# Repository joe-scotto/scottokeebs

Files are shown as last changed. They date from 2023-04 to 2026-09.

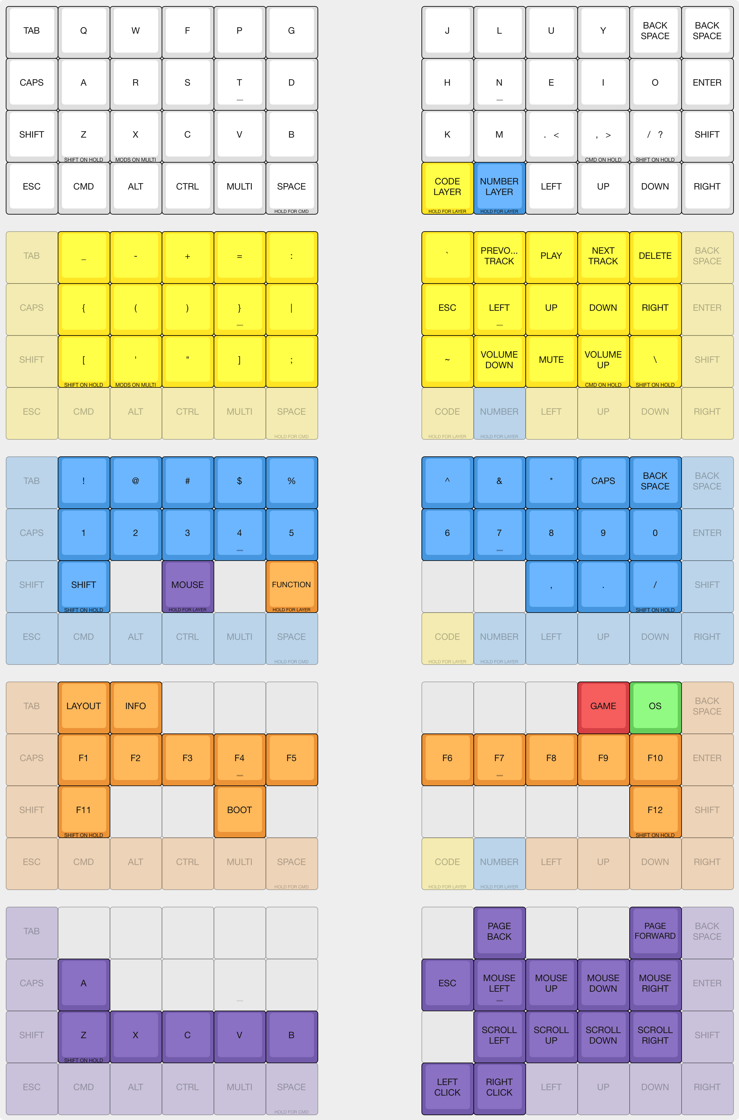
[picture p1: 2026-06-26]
Scotto48/PCB/Firmware/scotto.png

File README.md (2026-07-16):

png

Joe Scotto with his keyboards

ScottoKeebs at its core is an extensive collection of freely available handwired keyboard and macropad projects. It was started in September of 2022 and since then over 19 projects have been released. Most of them fit on a common 220x220mm 3D printer, require minimal support material, and use either an Arduino Pro Micro or a more powerful Raspberry Pi Pico.

# Navigation

-   [Website](https://scottokeebs.com)
-   [Keyboards](https://scottokeebs.com/blogs/keyboards)
-   [Macropads](https://scottokeebs.com/blogs/macropads)
-   [Extras](https://github.com/joe-scotto/scottokeebs/tree/main/Extras)
-   [Discord](https://discord.gg/vN6X3z8eyv)
-   [YouTube](https://youtube.com/joe_scotto)
-   [Recommendations](https://scottokeebs.com/pages/recommendations)
-   [Handwiring](https://www.youtube.com/watch?v=hjml-K-pV4E)
-   [Shop](https://www.youtube.com/watch?v=hjml-K-pV4E)

# Supporting

The ScottoKeebs project is released entirely for free and always will be, however, the development of new boards is completely out of my own pocket. It’s not a particularly expensive project to maintain but does involve quite a bit of time between prototyping and making content related to them.

**If you happen to really enjoy what I do and want to support me, consider [donating](https://donate.stripe.com/eVa14Yev83SmavmbII), [becoming a patron](https://patreon.com/joe_scotto), or purchasing something from my [shop](https://www.scottokeebs.com/shop).**

# License

</a></p>

<p xmlns:cc="http://creativecommons.org/ns#" xmlns:dct="http://purl.org/dc/terms/"><a property="dct:title" rel="cc:attributionURL" href="https://github.com/joe-scotto/scottokeebs">ScottoKeebs</a> by <a rel="cc:attributionURL dct:creator" property="cc:attributionName" href="https://github.com/joe-scotto">Joe Scotto</a> is licensed under <a href="http://creativecommons.org/licenses/by-nc-sa/4.0/?ref=chooser-v1" target="_blank" rel="license noopener noreferrer" style="display:inline-block;">CC BY-NC-SA 4.0

_If you plan on converting a ScottoKeeb to a PCB, I would prefer you don't release the production or design files publicly in order to prevent people from stealing and selling my designs._

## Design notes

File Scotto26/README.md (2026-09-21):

# Scotto26 (SK46)

The Scotto26 is a 26-key split 3x4 keyboard that uses combos for the inner column on a normal layout.

You can read more about the components and how to build it [here](https://scottokeebs.com/blogs/keyboards/scotto26).

Scotto26

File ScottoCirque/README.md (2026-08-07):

# ScottoCirque (SK45)

The ScottoCirque is a 40mm Cirque Glidepoint trackpad module.

You can read more about the components and how to build it [here](https://scottokeebs.com/blogs/macropads/scottocirque).

scottocirque

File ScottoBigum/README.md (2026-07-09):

# ScottoBigum (SK45)

The ScottoBigum is a 17-key wireless macropad scaled up 4 times the normal size and arguably a world record.

You can read more about the components and how to build it [here](https://scottokeebs.com/blogs/macropads/scottobigum-handwired-macropad).

scottobigum

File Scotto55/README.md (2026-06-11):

# Scotto55 (SK42)

The Scotto55 is a 55-key split monoblock ergonomic keyboard with a large center rotary encoder.

You can read more about the components and how to build it [here](https://scottokeebs.com/blogs/keyboards/scotto55-handwired-keyboard).

Scotto55

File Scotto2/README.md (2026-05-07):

# Scotto2 (SK43)

The Scotto2 is a 2 key large button gamepad designed for accessibility.

You can read more about the components and how to build it [here](https://scottokeebs.com/blogs/macropads/scotto2-handwired-macropad).

IMG_6516 Large

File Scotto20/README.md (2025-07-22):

# Scotto20 (SK36)

The Scotto20 is a 20-key macropad.

You can read more about the components and how to build it [here](https://scottokeebs.com/blogs/macropads/scotto20-handwired-macropad).

Scotto20

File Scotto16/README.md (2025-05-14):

# Scotto16 (SK34)

The Scotto16 is a 16-key macropad.

You can read more about the components and how to build it [here](https://scottokeebs.com/blogs/macropads/scotto16-handwired-macropad).

Scotto16

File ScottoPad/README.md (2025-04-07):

# ScottoPad (SK33)

The ScottoPad is an 18-key wireless macropad.

You can read more about the components and how to build it [here](https://scottokeebs.com/blogs/macropads/scottopad-handwired-macropad).

ScottoPad

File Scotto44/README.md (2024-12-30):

# Scotto44 (SK32)

The Scotto44 is a 3x5 (38-keys) or 3x6 (44-keys) split column-staggered keyboard that uses a USB-C cable for the interconnect and has a large 3u action button.

You can read more about the components and how to build it [here](https://scottokeebs.com/blogs/keyboards/scotto44-handwired-keyboard).

Scotto44

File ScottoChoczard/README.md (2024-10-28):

# ScottoChoczard (SK31)

The ScottoChoczard is a wireless split 3x6 ortholinear keyboard that uses Choc switches and a large 750mah battery.

You can read more about the components and how to build it [here](https://scottokeebs.com/blogs/keyboards/scottochoczard-handwired-keyboard).

ScottoChoczard

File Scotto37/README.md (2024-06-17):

# Scotto37 (SK27)

The Scotto37 is a 37-key gasket-mounted 0.25u row-staggered keyboard with a 3u spacebar.

You can read more about the components and how to build it [here](https://scottokeebs.com/blogs/keyboards/Scotto37-handwired-keyboard).

scotto37

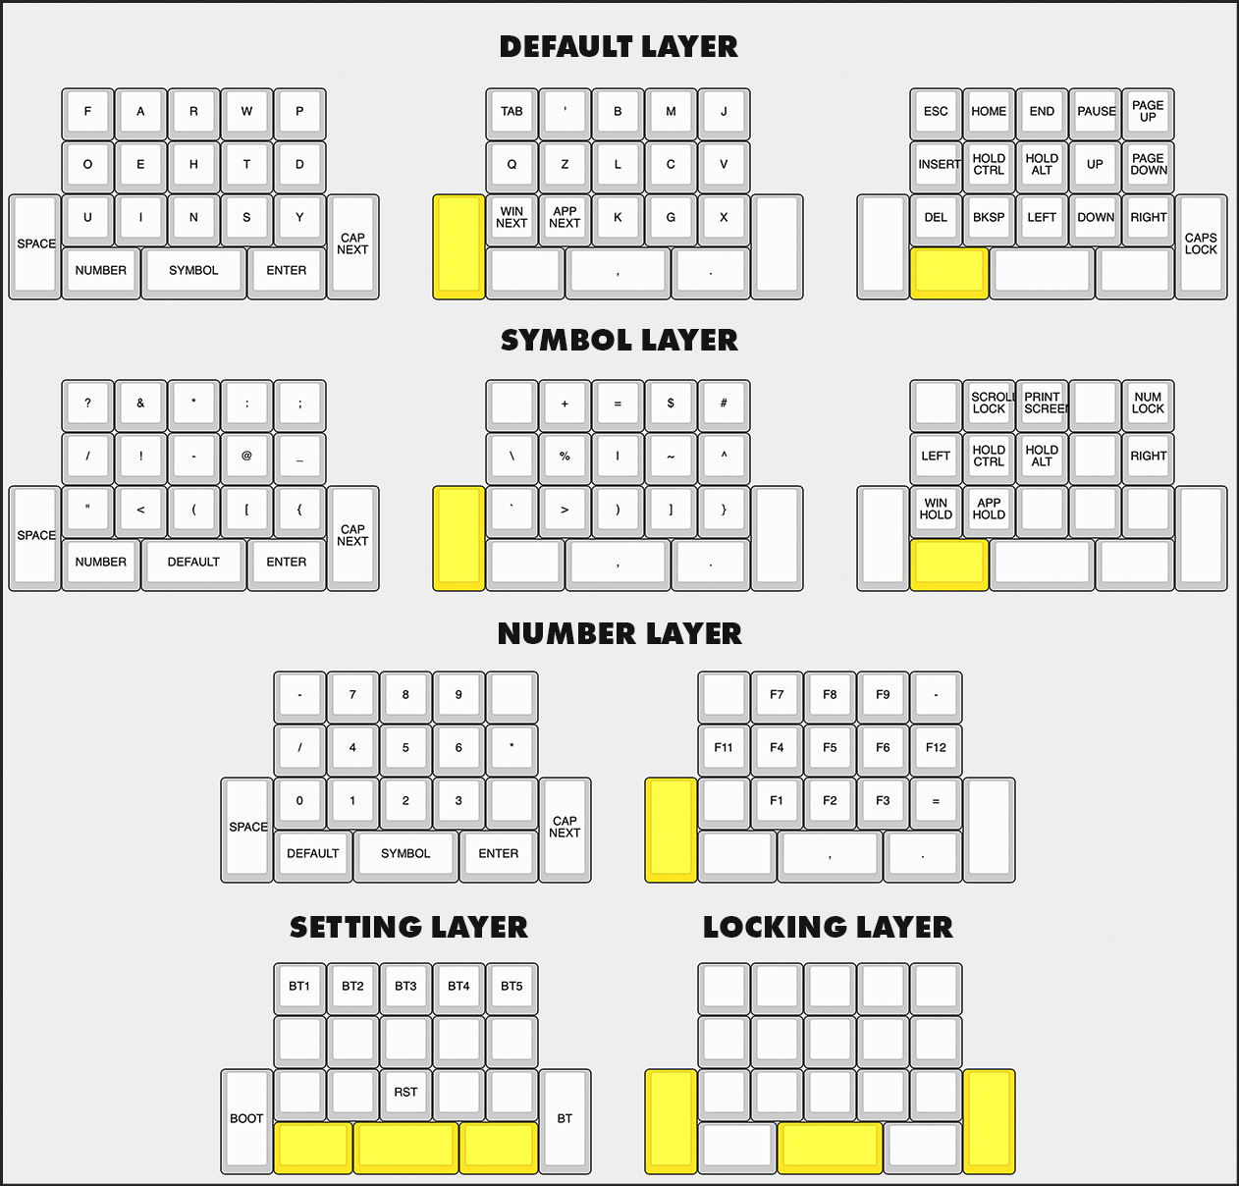
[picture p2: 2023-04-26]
ScottoFrog/Handwired/Firmware/scottofrog.jpg

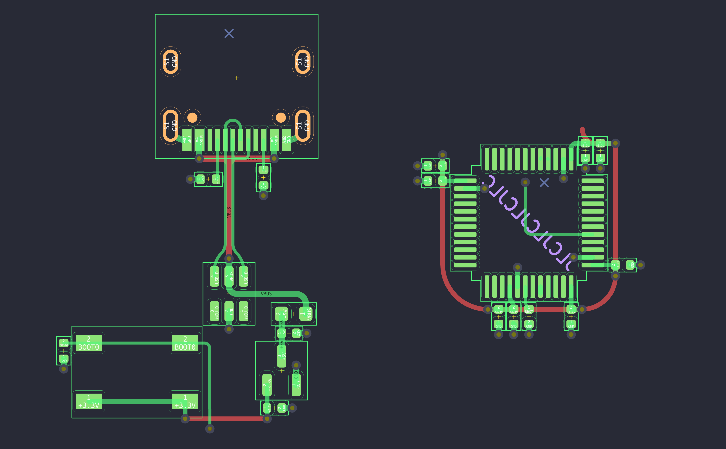
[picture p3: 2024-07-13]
Extras/ScottoModules/STM32F072CBT6/meta/scottomodules.png

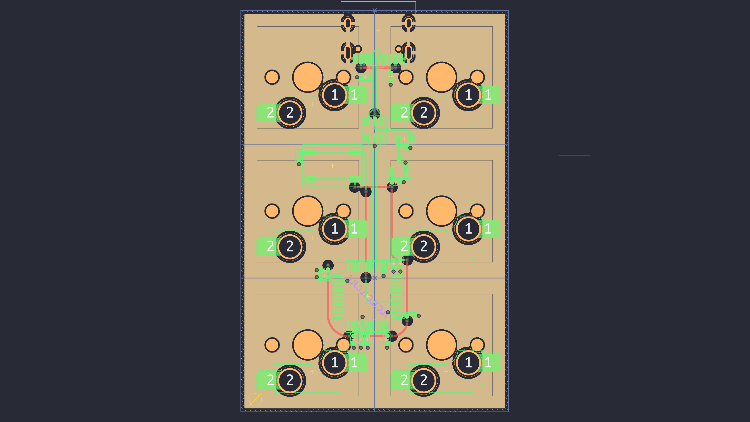
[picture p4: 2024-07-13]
Extras/ScottoModules/STM32F072CBT6/meta/matrix.png

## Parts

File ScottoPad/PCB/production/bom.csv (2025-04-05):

Designator | Footprint | Quantity | Value | LCSC Part #
C0, C1, C2, C3, C4, C5, R0, R1, R2 | TestPoint | 9 | TestPoint
D1, D10, D11, D12, D13, D14, D15, D16, D17, D18, D2, D3, D4, D5, D6, D7, D8, D9 | Diode_SOD-123 | 18 | Diode
S1, S10, S11, S12, S13, S14, S15, S16, S17, S18, S2, S3, S4, S5, S6, S7, S8, S9 | MX_Solder_1.00u | 18 | Keyswitch

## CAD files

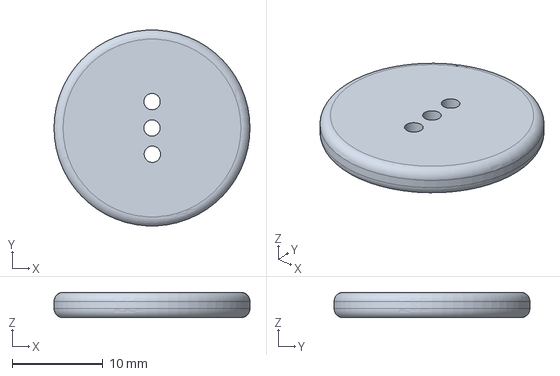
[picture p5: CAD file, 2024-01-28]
Extras/ScottoBender/ScottoBender - Cutter.step
21.6 x 21.6 x 2.80 mm

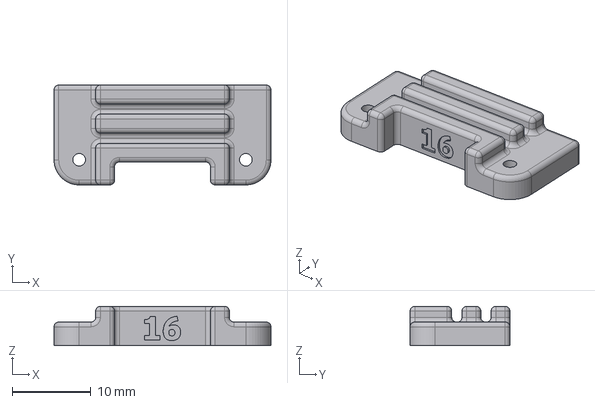
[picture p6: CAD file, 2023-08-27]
Extras/ScottoBender/V1/ScottoBender - ScottoBender (16g).step
27.6 x 12.7 x 5.00 mm

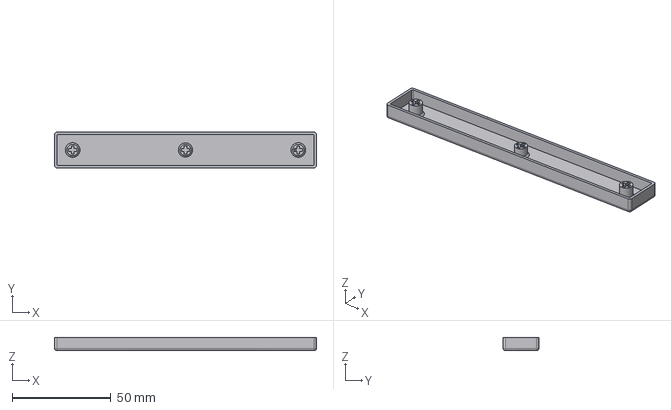
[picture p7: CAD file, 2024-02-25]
Extras/ScottoCaps/Flat/Blanks/ScottoCaps (Flat) - Shapr3D 5.5 Parametric (1)_7.00u.step
132.4 x 18.0 x 6.70 mm

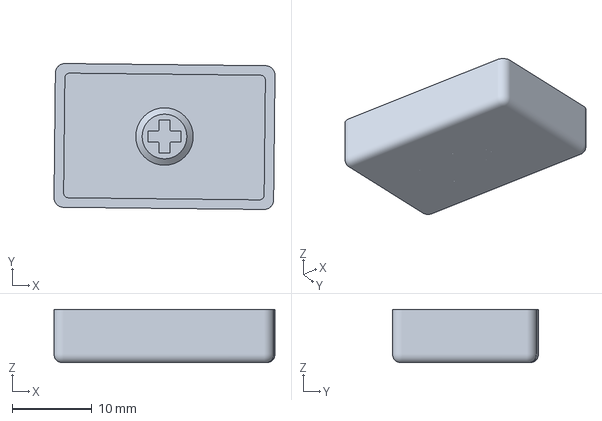
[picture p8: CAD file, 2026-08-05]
Extras/ScottoCaps/Flat/Legends/Alt (1.50u).3mf
27.7 x 18.3 x 6.70 mm

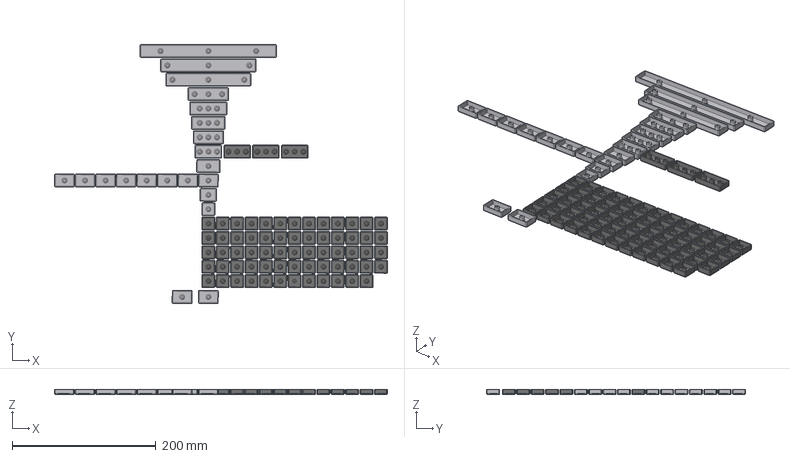
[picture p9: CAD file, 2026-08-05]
Extras/ScottoCaps/Flat/ScottoCaps (Flat).step
463.0 x 360.2 x 6.70 mm
Windows (1.50u)
Delete (1.50u)
Tab (1.50u)
Shift (1.50u)
Control (1.50u)
Alt (1.50u)
Caps Lock (1.50u)
No (1.50u)
Yes (1.50u)
Tilde
0 (2.00u)
Backspace
Tab
Q
W
F
P
G
J
L
U
Y
Semicolon
Slash
FSlash
Enter
Enter (2.00u)
A
R
S
T
D
H
N
E
I
O
Quote
LShift
Z
X
C
V
B
K
M
Less
Greater
Question
RShift
Hexagon1
Triangle1
Circle1
Square1
Hexagon2
Triangle2
Circle2
Square2
Left
Up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

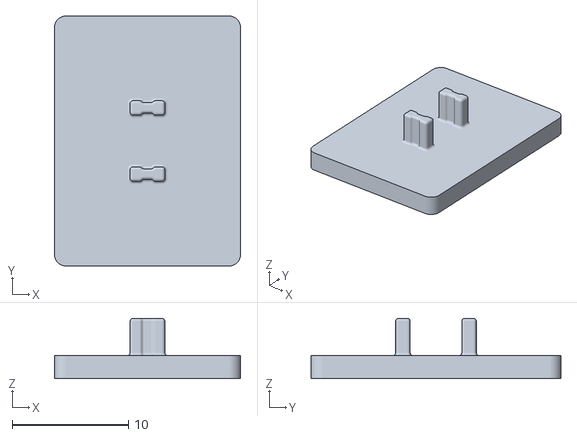
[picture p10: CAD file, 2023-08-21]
Extras/ScottoCaps/Glass/Choc/ScottoCaps (Glass) - 1.25u.stl
16.0 x 21.5 x 5.20

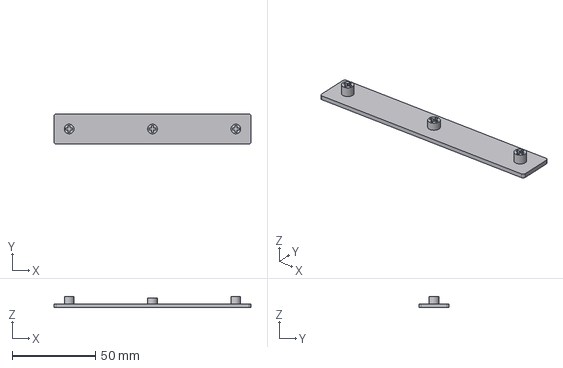
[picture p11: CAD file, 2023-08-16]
Extras/ScottoCaps/Glass/MX/ScottoCaps (Glass) - 6.25u.step
118.2 x 18.2 x 6.60 mm

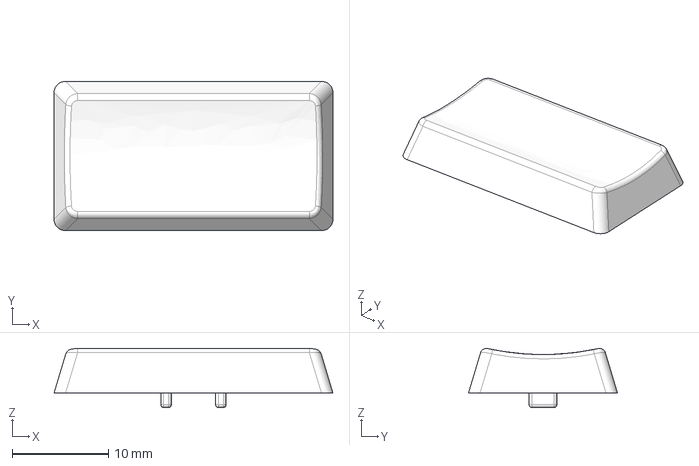
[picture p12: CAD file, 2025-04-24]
Extras/ScottoCaps/Scooped/Choc/Blanks/16x16/1.75u (16x16 - Concave).step
29.0 x 15.5 x 6.14 mm

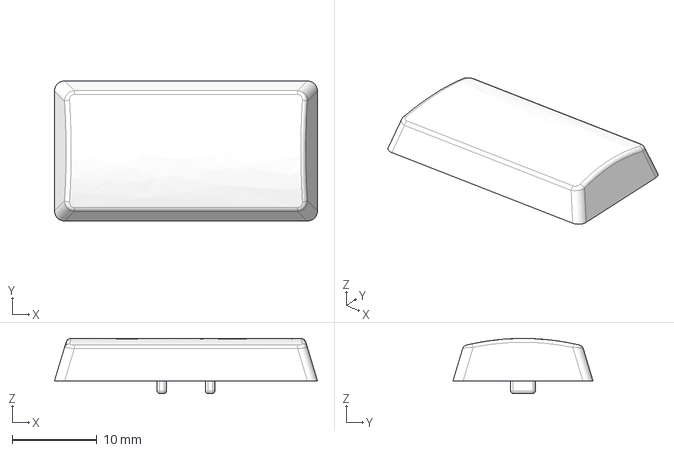
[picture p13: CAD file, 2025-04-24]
Extras/ScottoCaps/Scooped/Choc/Blanks/18x17/1.75u (18x17 - Convex).step
31.0 x 16.5 x 6.50 mm

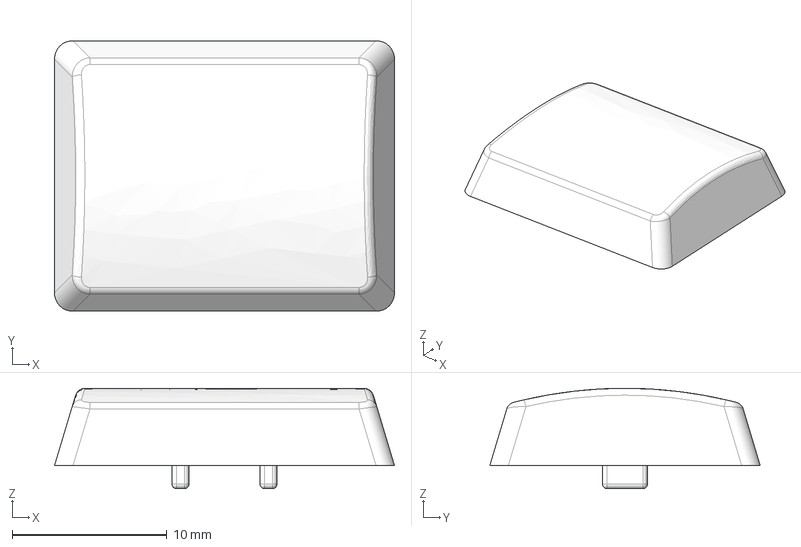
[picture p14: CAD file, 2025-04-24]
Extras/ScottoCaps/Scooped/Choc/Blanks/18x18/1.25u (18x18 - Convex).step
22.0 x 17.5 x 6.50 mm

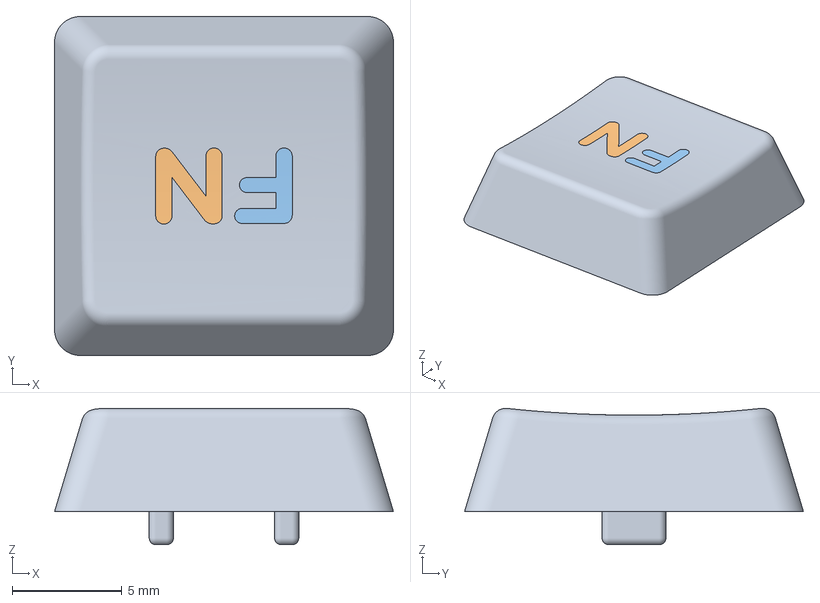
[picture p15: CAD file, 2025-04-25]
Extras/ScottoCaps/Scooped/Choc/Legends/16x16/Function - Text (16x16).3mf
15.4 x 15.4 x 6.20 mm
Keycap
N
F

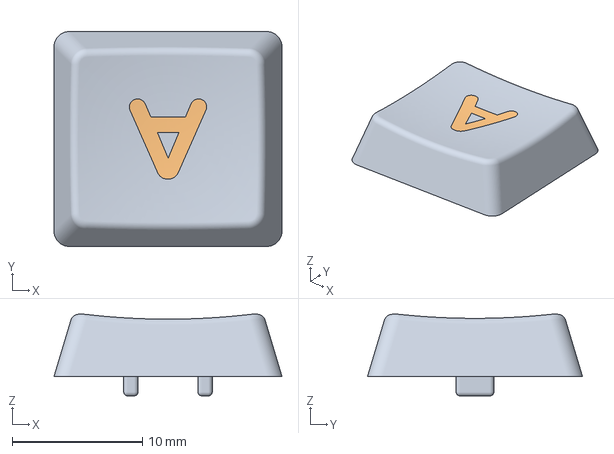
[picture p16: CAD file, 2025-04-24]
Extras/ScottoCaps/Scooped/Choc/Legends/18x17/A (18x17).3mf
17.5 x 16.5 x 6.28 mm
Keycap
Legend

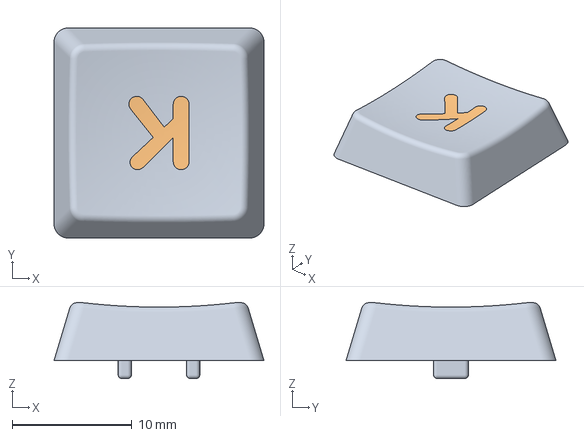
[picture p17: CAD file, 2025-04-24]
Extras/ScottoCaps/Scooped/Choc/Legends/18x18/K (18x18).3mf
17.5 x 17.5 x 6.33 mm
Keycap
Legend

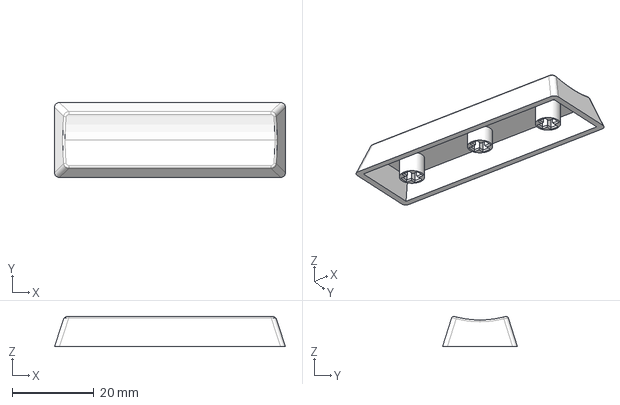
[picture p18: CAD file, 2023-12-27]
Extras/ScottoCaps/Scooped/MX/Blanks/3.00u (Concave).step
56.4 x 18.3 x 7.39 mm

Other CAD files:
Extras/ScottoCaps/Scooped/MX/Legends/Shift (1.50u).3mf
Extras/ScottoCaps/Scooped/MX/Raw/Concave Cutter.step
Extras/ScottoCaps/Scooped/MX/ScottoCaps (Scooped - MX) - Raw.step
Extras/ScottoCaps/ScottoCaps - 2.50u.step
Extras/ScottoBender/Bambu.3mf
Extras/ScottoBender/ScottoBender - Bottom.3mf
Extras/ScottoBender/ScottoBender - Bottom.step
Extras/ScottoBender/ScottoBender - Cutter.3mf
Extras/ScottoBender/ScottoBender - Middle.3mf
Extras/ScottoBender/ScottoBender - Middle.step
Extras/ScottoBender/ScottoBender - Top (Symbol).3mf
Extras/ScottoBender/ScottoBender - Top (Symbol).step
Extras/ScottoBender/ScottoBender - Top.3mf
Extras/ScottoBender/ScottoBender - Top.step
Extras/ScottoBender/V1/ScottoBender - ScottoBender (16g).stl
Extras/ScottoBender/V1/ScottoBender - ScottoBender (18g).step
Extras/ScottoBender/V1/ScottoBender - ScottoBender (18g).stl
Extras/ScottoCaps/Flat/Blanks/1.00u.3mf
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

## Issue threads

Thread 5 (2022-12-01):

Incorrect link

viciousdrop, 2022-12-01:
Hey dude love your stuff. Getting ready to build your 36 board over the Christmas break.

The link in your keyboard read me for Scotto starter goes to Scotto alp. Thought you want to know. Cheers

joe-scotto, 2022-12-16:
Not sure how I never got the notification for this but I fixed it tonight.

Thanks!

Closed 2022-12-16.

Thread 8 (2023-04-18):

Latest Scotto 9 plate files missing screw holes

ValerianClerc, 2023-04-18:
The [latest commit to the Scotto 9](https://github.com/joe-scotto/scottokeebs/commit/64fd981946e17bfb1748774849abb6b54c125160) case/plate `.stl` files has removed the screw holes in the plate.

[Before](https://github.com/joe-scotto/scottokeebs/blob/6471538663b09b30d701e398841e1ddb5251c313/Scotto9/Case/Scotto9%20-%20Plate.stl):
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

[After](https://github.com/joe-scotto/scottokeebs/blob/main/Scotto9/Case/Scotto9%20-%20Plate.stl) (current):
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

joe-scotto, 2023-04-18:
Thank you, fixed in [d236eca](https://github.com/joe-scotto/scottokeebs/commit/d236eca8e393410f7d84a18d1b41dc769da98818).

Closed 2023-04-18.

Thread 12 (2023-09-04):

3D files for Scotto34 PCB Edition?

bobwulff, 2023-09-04:
https://github.com/joe-scotto/scottokeebs/tree/main/Scotto34/PCB

joe-scotto, 2023-09-04:
I made the decision for my PCB boards to close-source everything but the firmware since I release all my [handwired](https://scottokeebs.com/blogs/keyboards) boards completely free.

That said, the Scotto34 is simple enough to design a case on your own if you wanted :)

Closed 2023-09-04.

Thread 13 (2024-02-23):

KiCad files in their own repo

rsescu, 2024-02-23:
Hi. Nice project, love your vids! Just a question, have you considered splitting Extras/ScottoKicad/ into it's own repository. Might be a cool idea to try and get it published as a plugin?

joe-scotto, 2024-02-23:
I thought about it when I put everything together but I instead decided to keep it here as it makes it easier to just link one thing with everything.

Maybe one day I'll look into making it a plugin but no plans currently.

marcuswu, 2024-07-11:
Perhaps use a [git submodule](https://git-scm.com/book/en/v2/Git-Tools-Submodules) to link the KiCad files back?

joe-scotto, 2024-07-12:
Submodules might actually be the solution I look into soon as the repo is starting to approach the 2gb limit. The problem and reason I haven't done anything is that my videos, specifically for Kicad, all show downloading the project and that wouldn't work with submodules. Might be just as simple as linking the new submodule underneath the video.

The other issue with this method is that it starts making it more complex for me to manage. The way I work now is that I just push everything to `ScottoKeebs` because it makes my life easier. In the next few months I'll take a deeper look at this because I am very close to hitting the repo size limit.

marcuswu, 2024-07-19:
I was thinking about it more, and if you wanted the Kicad components under a separate license, it would be nicer under a separate repo. For instance, in order to clear the legality of utilizing these components within a commercial keyboard -- it's clear you don't want the keyboards you've designed sold commercially without making a deal with you, but is it ok to use the Kicad libraries to design a unique design and sell that commercially? If that is the intent, a separate license file within a directory can work, but a separate repository with a different license is clearer.

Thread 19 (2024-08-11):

Release Bambu Studio file for your keycaps?

Avaviel, 2024-08-11:
I am attempting to print your keycaps in multicolors, but I'm having issues with the import. Some of the files import to the program badly, and move around. Could you happen to share your 3mf file for the keycaps?

https://github.com/joe-scotto/scottokeebs/tree/main/Extras/ScottoCaps/Scooped/MX/Legends

joe-scotto, 2024-08-11:
It already exists here: https://github.com/joe-scotto/scottokeebs/blob/main/Extras/ScottoCaps/Scooped/MX/Alphas.3mf

I won't be adding anything additionally though, it's a lot of work to manage all that but this should be a good enough start.

Closed 2024-08-11.

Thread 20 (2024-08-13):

Unable to see Placeholder Symbols

justinreddick, 2024-08-13:
I recently downloaded the repo to start learning KiCAD and started following the PCB Desgin playlist. I was unable to find the Placehodler_ objects used in the videos although the files have them defined (i.e Placeholder_Diode is missing)
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

joe-scotto, 2024-08-13:
This is a Kicad but that still hasn't been fixed. Instead of searching for the footprint or symbol you need, manually scroll to the library and open it. Everything should be there if you keep the search bar empty.

Closed 2024-08-13.

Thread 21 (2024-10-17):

Hot-swap sockets side issue

swift502, 2024-10-17:
Hi!

I have an issue where my choc hotswap sockets are on the front side

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

But obviously their solder pads are on the back.

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

As a result, `positions.csv` says they're on top:

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

And JLC doesn't recognize them for assembly on the correct side.
Flipping it with F doesn't work because it also flips horizontally, and puts the 3D model on top.

Is this correct? Any way to fix it? (Other than editing positions.csv manually)

swift502, 2024-10-17:
This is the ScottoKeebs_Hotswap:Hotswap_Choc_V1_1.00u footprint, but I think all choc hot swaps, and possibly other hotswaps are like this probably?

swift502, 2024-10-19:
I went with the solder footprint. Turns out configuring JLC assembly of hot swaps is more complicated than I expected.

Closed 2024-10-19.

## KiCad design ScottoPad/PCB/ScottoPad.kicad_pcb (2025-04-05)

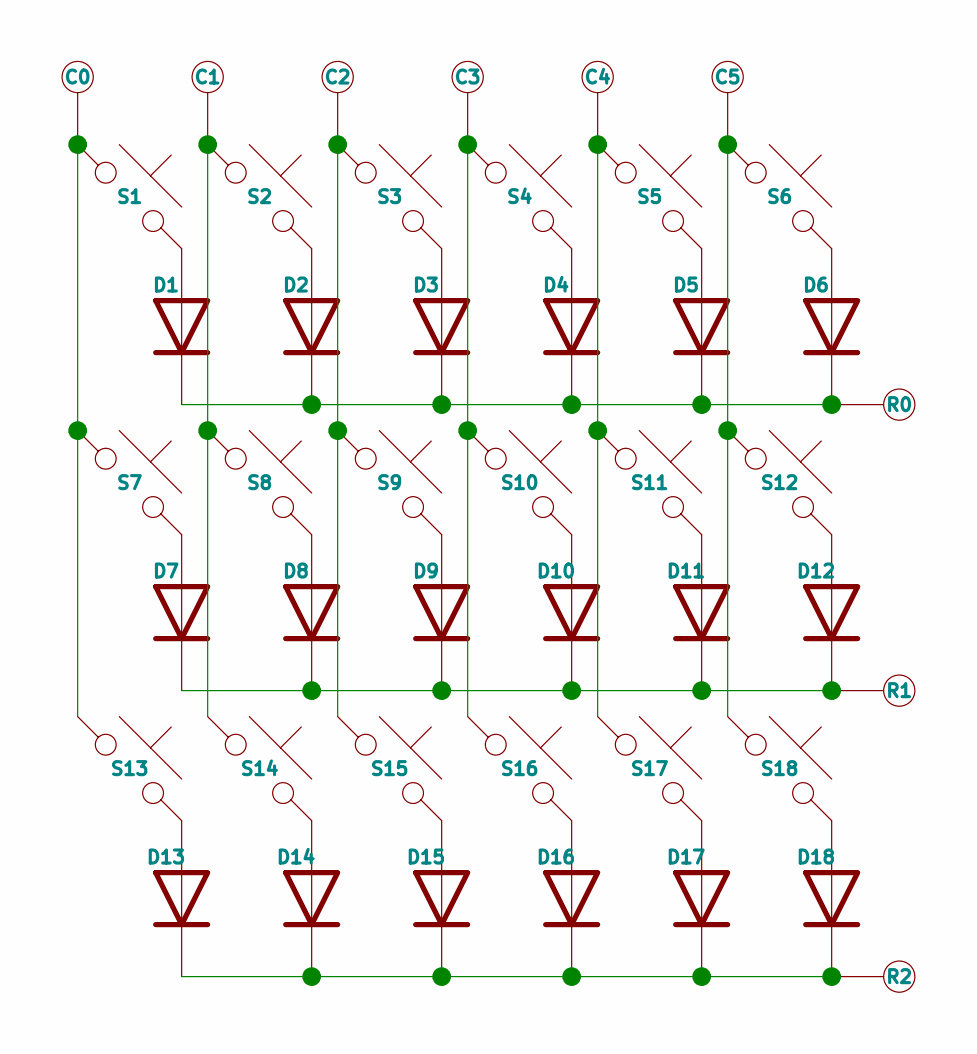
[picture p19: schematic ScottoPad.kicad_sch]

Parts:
C0, C1, C2, C3, C4, C5: TestPoint
D1, D2, D3, D4, D5, D6, D7, D8, D9, D10, D11, D12, D13, D14, D15, D16, D17, D18: Diode; Diode_SOD-123
R0, R1, R2: TestPoint
S1, S2, S3, S4, S5, S6, S7, S8, S9, S10, S11, S12, S13, S14, S15, S16, S17, S18: Keyswitch; MX_Solder_1.00u

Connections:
unnamed: C0.1, S1.1, S7.1, S13.1
unnamed: C1.1, S2.1, S8.1, S14.1
unnamed: C2.1, S3.1, S9.1, S15.1
unnamed: C3.1, S4.1, S10.1, S16.1
unnamed: C4.1, S5.1, S11.1, S17.1
unnamed: C5.1, S6.1, S12.1, S18.1
unnamed: D1.2 (A), S1.2
unnamed: D1.1 (K), D2.1 (K), D3.1 (K), D4.1 (K), D5.1 (K), D6.1 (K), R0.1
unnamed: D2.2 (A), S2.2
unnamed: D3.2 (A), S3.2
unnamed: D4.2 (A), S4.2
unnamed: D5.2 (A), S5.2
unnamed: D6.2 (A), S6.2
unnamed: D7.2 (A), S7.2
unnamed: D8.2 (A), S8.2
unnamed: D9.2 (A), S9.2
unnamed: D10.2 (A), S10.2
unnamed: D7.1 (K), D8.1 (K), D9.1 (K), D10.1 (K), D11.1 (K), D12.1 (K), R1.1
unnamed: D11.2 (A), S11.2
unnamed: D12.2 (A), S12.2
unnamed: D13.2 (A), S13.2
unnamed: D13.1 (K), D14.1 (K), D15.1 (K), D16.1 (K), D17.1 (K), D18.1 (K), R2.1
unnamed: D14.2 (A), S14.2
unnamed: D15.2 (A), S15.2
unnamed: D16.2 (A), S16.2
unnamed: D17.2 (A), S17.2
unnamed: D18.2 (A), S18.2

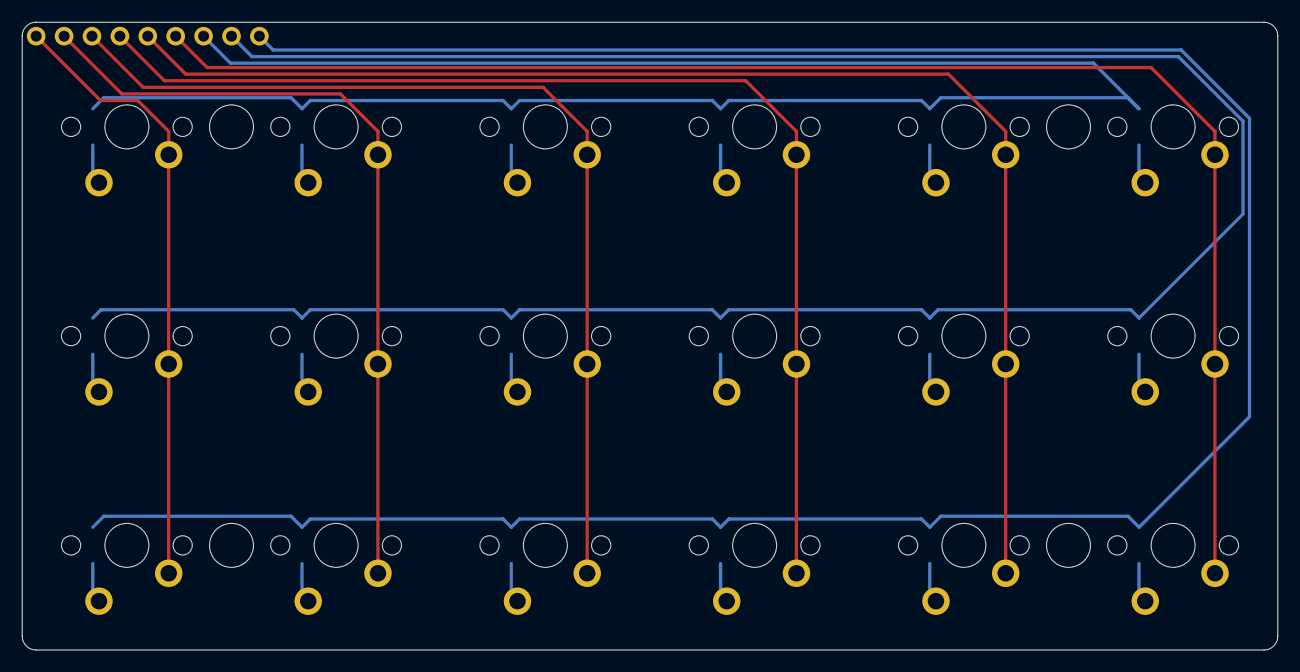
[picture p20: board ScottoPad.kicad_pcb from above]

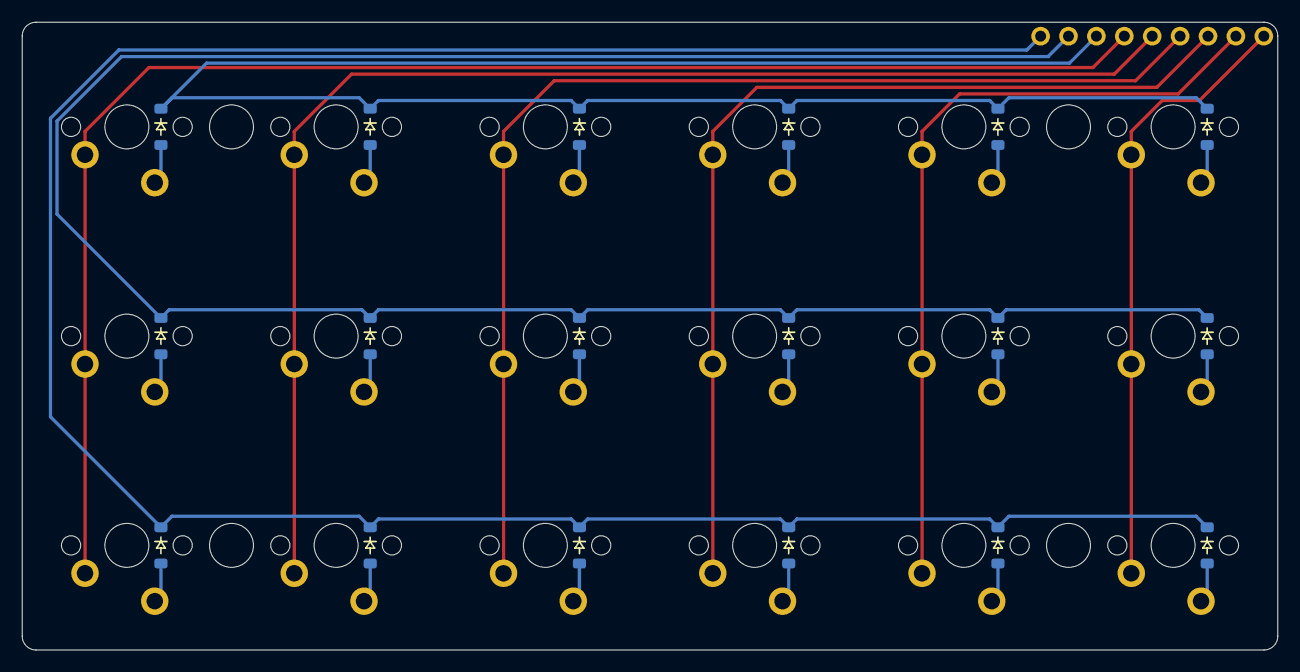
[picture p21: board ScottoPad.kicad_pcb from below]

Board: 2 copper layers, 114.3 x 57.2 mm, 45 parts (18 on the bottom side), 27 nets.

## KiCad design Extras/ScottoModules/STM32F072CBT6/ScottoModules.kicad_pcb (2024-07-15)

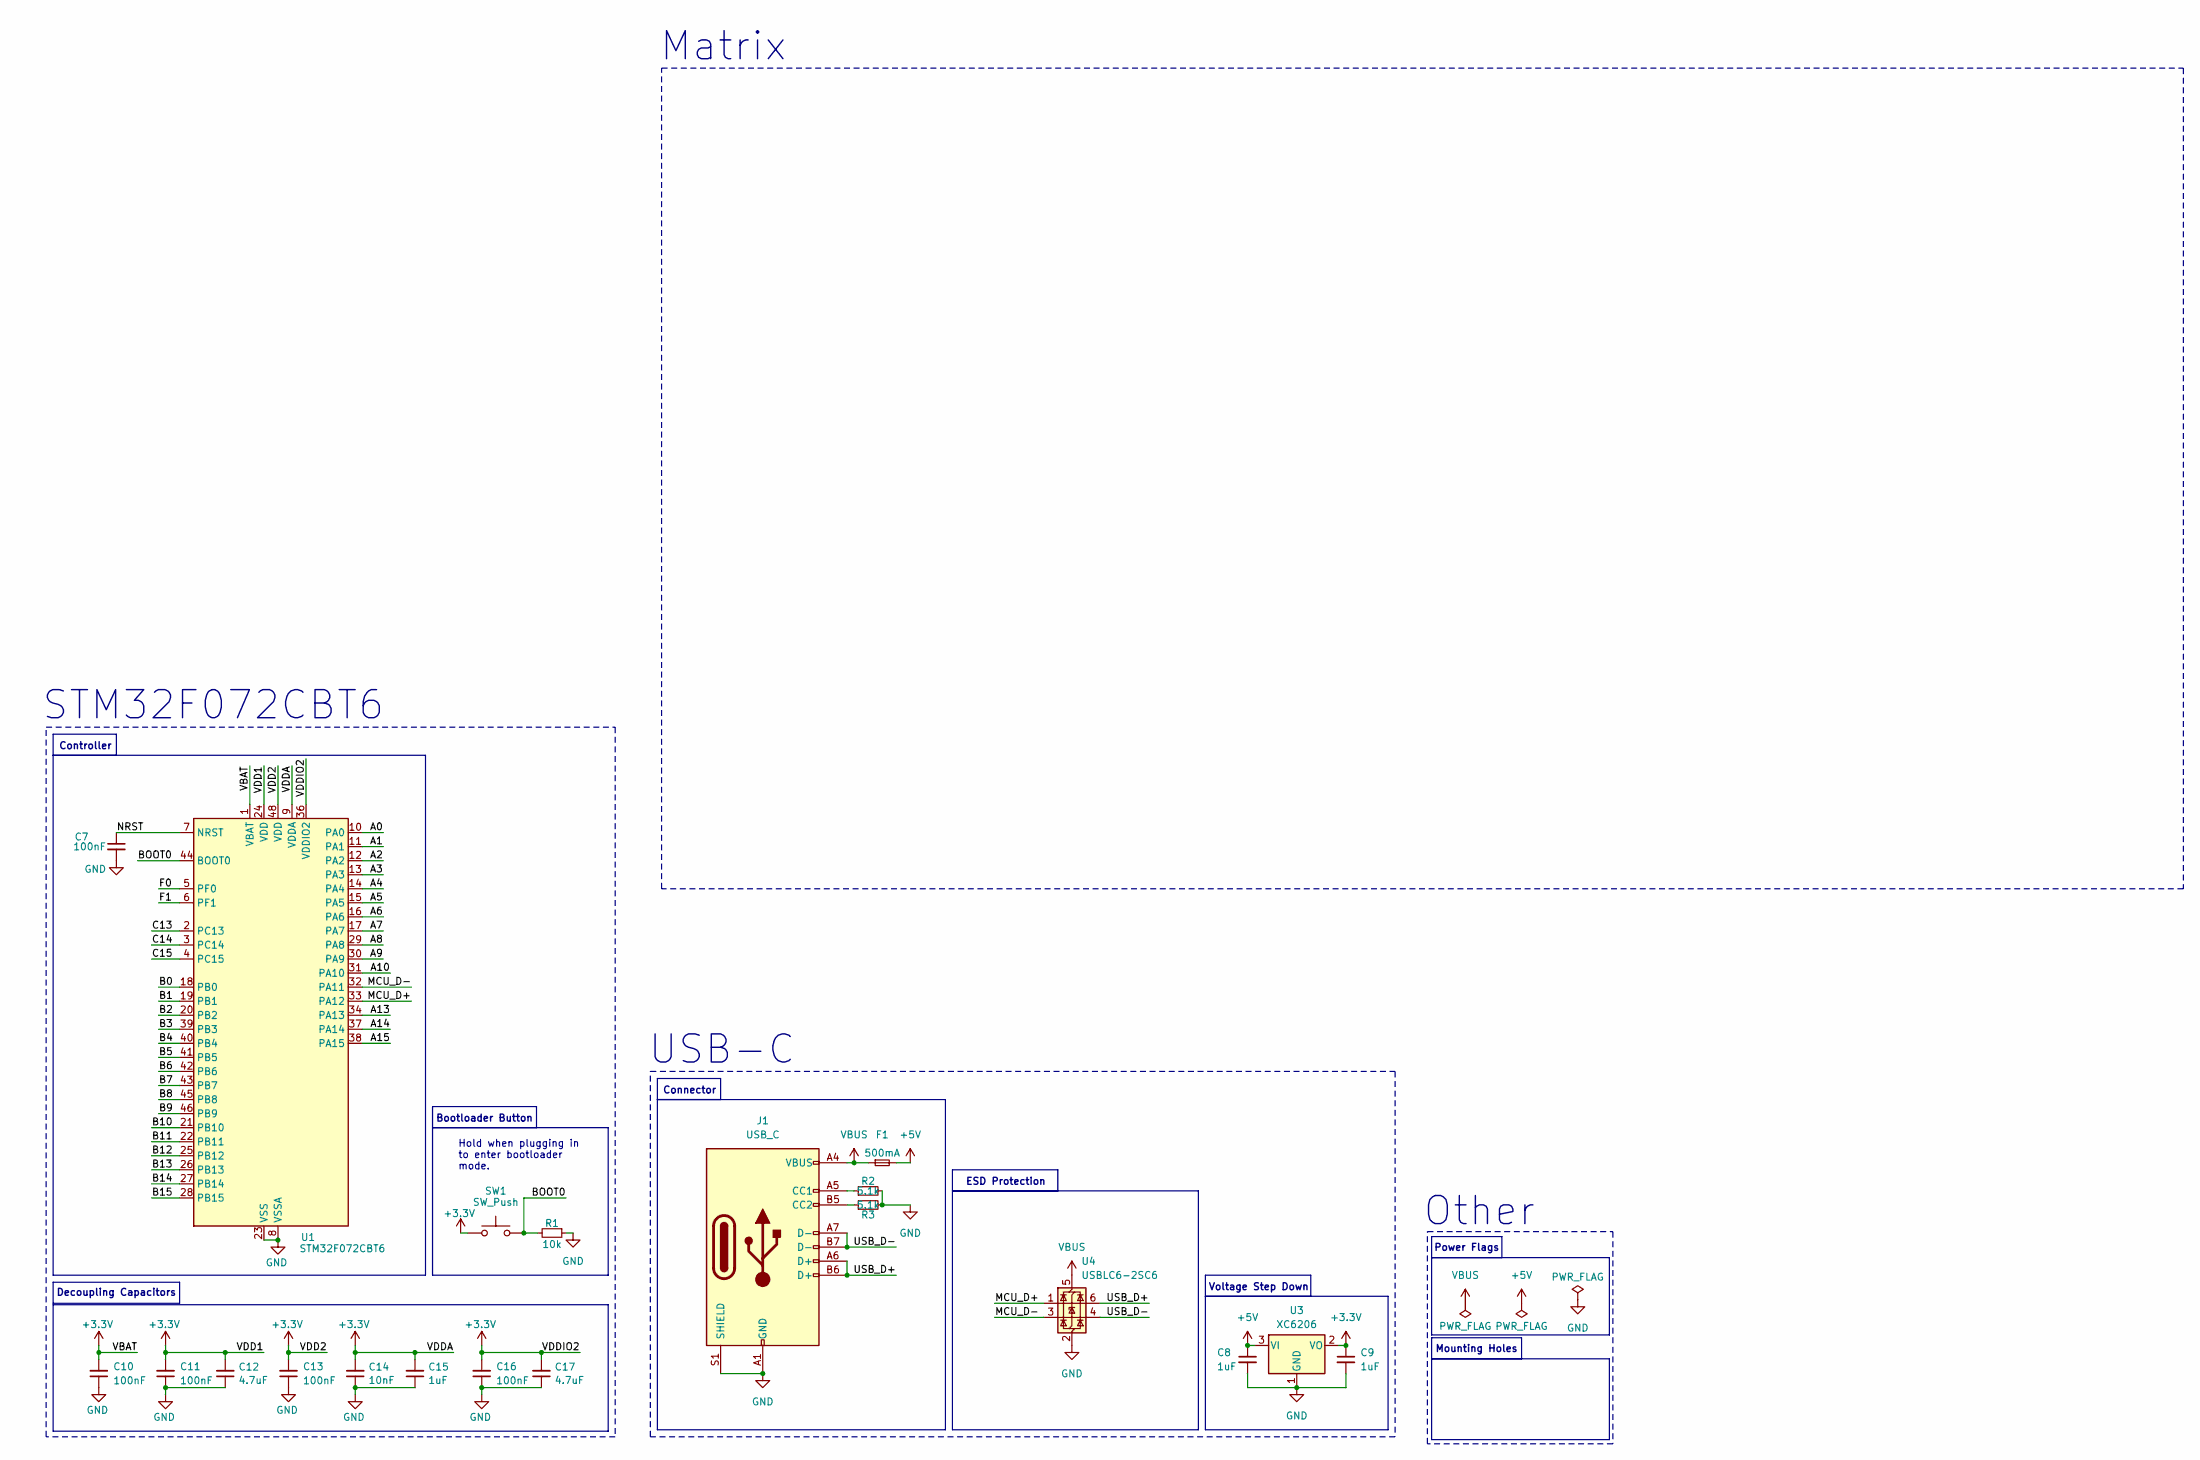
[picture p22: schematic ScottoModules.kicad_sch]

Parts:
C7: 100nF; Capacitor_0402; LCSC C307331
C8, C9: 1uF; Capacitor_0402; LCSC C52923
C10, C11, C13, C16: 100nF; Capacitor_0402; MPN CL05B104KB54PNC; LCSC C307331
C12, C17: 4.7uF; Capacitor_0402; MPN CL05A475MP5NRNC; LCSC C23733
C14: 10nF; Capacitor_0402; MPN CL05B103KB5NNNC; LCSC C15195
C15: 1uF; Capacitor_0402; MPN CL05A105KA5NQNC; LCSC C52923
F1: 500mA; Fuse_0603; LCSC C210357
J1: USB_C; USB_C_HRO_TYPE-C-31-M-12; LCSC C165948
R1: 10k; Resistor_0402; LCSC C25744
R2, R3: 5.1k; Resistor_0402; LCSC C25905
SW1: SW_Push; Button_TL3342; LCSC C115351
U1: STM32F072CBT6; Package_LQFP-48_7x7mm_P0.5; LCSC C81720
U3: XC6206; Voltage_SOT-23; LCSC C5446
U4: USBLC6-2SC6; ESD_SOT-23-6; LCSC C2827654

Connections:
+3.3V: C9.1, C10.2, C11.2, C12.2, C13.2, C14.2, C15.2, C16.2, C17.2, SW1.1, U1.1 (VBAT), U1.9 (VDDA), U1.24 (VDD), U1.36 (VDDIO2), U1.48 (VDD), U3.2 (VO)
+5V: C8.1, F1.2, U3.3 (VI)
/A0: U1.10 (PA0)
/A1: U1.11 (PA1)
/A2: U1.12 (PA2)
/A3: U1.13 (PA3)
/A4: U1.14 (PA4)
/A5: U1.15 (PA5)
/A6: U1.16 (PA6)
/A7: U1.17 (PA7)
/A8: U1.29 (PA8)
/A9: U1.30 (PA9)
/A10: U1.31 (PA10)
/A13: U1.34 (PA13)
/A14: U1.37 (PA14)
/A15: U1.38 (PA15)
/B0: U1.18 (PB0)
/B1: U1.19 (PB1)
/B2: U1.20 (PB2)
/B3: U1.39 (PB3)
/B4: U1.40 (PB4)
/B5: U1.41 (PB5)
/B6: U1.42 (PB6)
/B7: U1.43 (PB7)
/B8: U1.45 (PB8)
/B9: U1.46 (PB9)
/B10: U1.21 (PB10)
/B11: U1.22 (PB11)
/B12: U1.25 (PB12)
/B13: U1.26 (PB13)
/B14: U1.27 (PB14)
/B15: U1.28 (PB15)
/BOOT0: R1.2, SW1.2, U1.44 (BOOT0)
/C13: U1.2 (PC13)
/C14: U1.3 (PC14)
/C15: U1.4 (PC15)
/F0: U1.5 (PF0)
/F1: U1.6 (PF1)
/MCU_D+: U1.33 (PA12), U4.1 (I/O1)
/MCU_D-: U1.32 (PA11), U4.3 (I/O2)
/NRST: C7.1, U1.7 (NRST)
/USB_D+: J1.A6 (D+), J1.B6 (D+), U4.6 (I/O1)
/USB_D-: J1.A7 (D-), J1.B7 (D-), U4.4 (I/O2)
GND: C7.2, C8.2, C9.2, C10.1, C11.1, C12.1, C13.1, C14.1, C15.1, C16.1, C17.1, J1.A1 (GND), J1.A12 (GND), J1.B1 (GND), J1.B12 (GND), J1.S1 (SHIELD), R1.1, R2.2, R3.2, U1.8 (VSSA), U1.23 (VSS), U1.35 (VSS), U1.47 (VSS), U3.1 (GND), U4.2 (GND)
unnamed: J1.A5 (CC1), R2.1
unnamed: J1.B5 (CC2), R3.1
VBUS: F1.1, J1.A4 (VBUS), J1.A9 (VBUS), J1.B4 (VBUS), J1.B9 (VBUS), U4.5 (VBUS)

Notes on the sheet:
Hold when plugging in to enter bootloader mode.
STM32F072CBT6
USB-C
Mounting Holes
Decoupling Capacitors
Controller
ESD Protection
Power Flags
Voltage Step Down
Other
Bootloader Button
Matrix
Connector

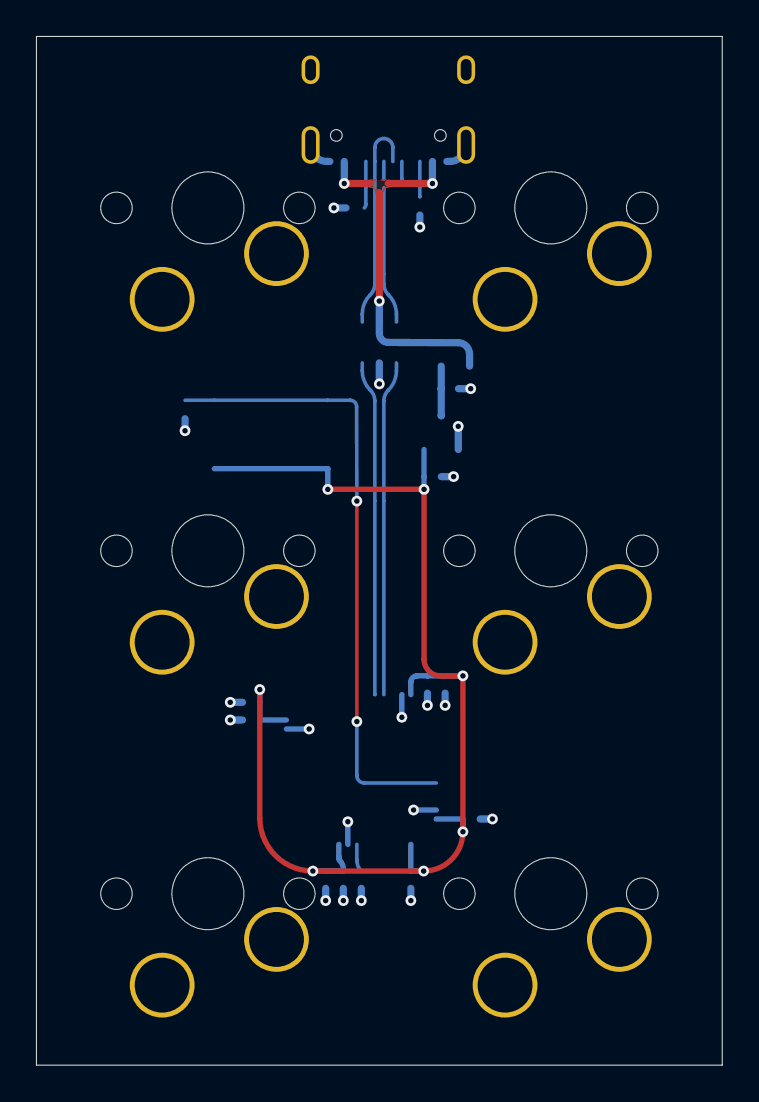
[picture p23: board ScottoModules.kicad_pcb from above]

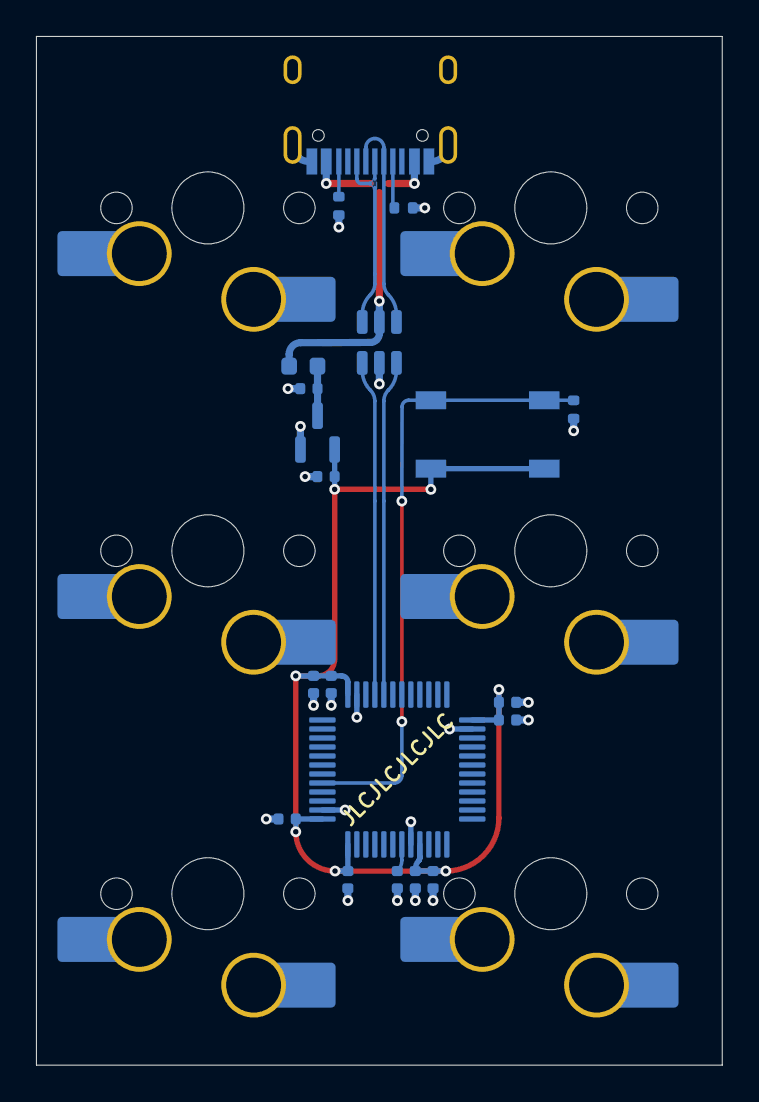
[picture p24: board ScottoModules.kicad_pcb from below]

Board: 4 copper layers, 38.1 x 57.2 mm, 20 parts (20 on the bottom side), 12 nets.

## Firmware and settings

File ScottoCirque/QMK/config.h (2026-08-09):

#pragma once

#define SPI_SCK_PIN GP2
#define SPI_MOSI_PIN GP3
#define SPI_MISO_PIN GP4
#define POINTING_DEVICE_CS_PIN GP5

#define CIRQUE_PINNACLE_DIAMETER_MM 40
#define POINTING_DEVICE_ROTATION_270
#define CIRQUE_PINNACLE_TAP_ENABLE
#define CIRQUE_PINNACLE_CIRCULAR_SCROLL_ENABLE

#define POINTING_DEVICE_INVERT_Y
#define POINTING_DEVICE_INVERT_X

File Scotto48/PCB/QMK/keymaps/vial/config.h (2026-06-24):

/*
Copyright 2023 Joe Scotto

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
You should have received a copy of the GNU General Public License
along with this program.  If not, see <http://www.gnu.org/licenses/>.
*/

#pragma once

// Define options
#define TAPPING_TERM 135
#define PERMISSIVE_HOLD
#define RGB_BRIGHTNESS 8

// Vial
#define VIAL_KEYBOARD_UID {0x62, 0x11, 0x1A, 0xB9, 0x84, 0x37, 0x7A, 0xF4}
#define VIAL_UNLOCK_COMBO_ROWS {3, 3}
#define VIAL_UNLOCK_COMBO_COLS {0, 11}
#define DYNAMIC_KEYMAP_LAYER_COUNT 5

// Mouse keys
#define MOUSEKEY_DELAY 0
#define MOUSEKEY_INTERVAL 16
#define MOUSEKEY_WHEEL_DELAY 0
#define MOUSEKEY_MAX_SPEED 7
#define MOUSEKEY_TIME_TO_MAX 40

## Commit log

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2021-01-26 Added Ortho48 case and Iris V4 middle layer Sharp3d file
    [Case.3mf, Ortho48 Case Cura.3mf, Ortho48 Case.stl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]
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2022-09-21 Start making ready for release
    [Accent Triangle.step, Accent Triangle.stl, Case.3mf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]
2022-09-21 Add Scotto40 case files
    [Scotto36 - Case.step, Scotto36 - Case.stl, Scotto36 - Plate.step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]
2022-09-21 Move some keebs out to main folder
    [Accent Triangle.step, Accent Triangle.stl, Case.step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]
2022-09-21 Add case files for Scotto9
    [Scotto9 - Case.step, Scotto9 - Case.stl, Scotto9 - Plate.step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]
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2022-09-24 Update plate to proper orientation
    [ScottoSlant - Plate.step, ScottoSlant - Plate.stl, ScottoSlant step - Plate.step]
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2022-09-26 Fix Spacing
    [ScottoCMD - Case.step, ScottoCMD - Case.stl, ScottoCMD - Plate.step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]
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2022-09-30 Rename ScottoSlant step - Plate.step to ScottoSlant - Plate.step
    [ScottoSlant - Plate.step]
2022-09-30 Add case files and kle files
    [24feac2025b9248a35d14bf5f67611dcf66123b1_switch.dxf, ScottoGame - Case.step, ScottoGame - Case.stl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]
2022-09-30 Update KLE location and names
    [Switch Plate.dxf]
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2022-10-01 Update case files to new OLED
    [ScottoGame - Case.step, ScottoGame - Case.stl, ScottoGame - OLED (Frame).step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]
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2022-10-03 Case naming consistency updates
    [ScottoAlp - Case.step, ScottoAlp - Case.stl, ScottoAlp - Plate.step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]
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2022-10-10 Add ScottoFly ergo keyboard
    [ScottoFly - Case.step, ScottoFly - Plate.step, ScottoFly - Plate.stl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]
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2022-12-19 Add plate files for ScottoNum
    [keyboard-layout.dxf]
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2022-12-20 Update ScottoNum case files
    [ScottoNum - Middle (0°).step, ScottoNum - Middle (0°).stl, ScottoNum - Middle (5°).step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]
2022-12-21 Update ScottoNum top for offset
    [ScottoNum - Top (0°).step, ScottoNum - Top (0°).stl, ScottoNum - Top (5°).step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]
2023-01-20 Update ScottoLong plate to correct one
    [ScottoLong - Plate.step, ScottoLong - Plate.stl]
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2023-04-10 Update Scotto40 to 20.6mm height
    [Scotto40 - Case.step, Scotto40 - Case.stl]
2023-04-10 Update Scotto36 to 20.6mm
    [Scotto36 - Case.step, Scotto36 - Case.stl]
2023-04-10 Update ScottoSlant to 20.6mm
    [ScottoSlant - Case.step]
2023-04-10 Update ScottoCMD to 20.6mm
    [ScottoCMD - Case.step, ScottoCMD - Case.stl, ScottoCMD - Plate.step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]
2023-04-11 Update Scotto9 to 20.6mm from 19mm
    [Scotto9 - Case.step, Scotto9 - Case.stl, Scotto9 - Plate.step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]
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2023-05-20 Move handwired variant of Scotto34 to directory
    [Scotto34 - Bottom.step, Scotto34 - Bottom.stl, Scotto34 - Case.step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]
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2023-05-31 Update ScottoLong to have shelf and variant for official pico or larger pico-like boards
    [ScottoLong - Case (16mb Board).step, ScottoLong - Case (16mb Board).stl, ScottoLong - Case (Official Pico).step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]
2023-05-31 Update ScottoLong case again
    [ScottoLong - Case (16mb Board).step, ScottoLong - Case (16mb Board).stl]
2023-05-31 Make ScottoMouse compatible with larger pico boards
    [ScottoLong - Case (Black Pico).step, ScottoLong - Case (Black Pico).stl, ScottoLong - Case (Green Pico).step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]
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2023-06-10 Update file origins for ScottoLong
    [ScottoLong - Case (Black Pico).step, ScottoLong - Case (Black Pico).stl, ScottoLong - Case (Green Pico).step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]
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2023-06-10 Update case files to remove plate taper
    [Scotto34 - Bottom.step, Scotto34 - Bottom.stl, Scotto34 - Case.step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]
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2023-06-10 Finalize Scotto36 (Needs case update still)
    [Scotto36 - Case.step, Scotto36 - Case.stl, Scotto36 - Plate.step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]
2023-06-10 Scotto36 Final Case files
    [Scotto36 - Case.step, Scotto36 - Case.stl, Scotto36 - Plate.step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]
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2023-06-13 Fix ScottoLong plate
    [ScottoLong - Plate.step, ScottoLong - Plate.stl]
2023-06-13 Fix taper
    [ScottoLong - Case (Green Pico).step, ScottoLong - Case (Green Pico).stl]
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2023-07-29 Make stabilizer 1mm taller
    [ScottoCaps - 1.00u.step, ScottoCaps - 1.25u.step, ScottoCaps - 1.50u.step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]
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2023-07-29 Add fillet to caps for stronger stem
    [ScottoCaps - 1.00u.step, ScottoCaps - 1.00u.stl, ScottoCaps - 1.25u.step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]
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2023-07-29 Fix hole
    [ScottoOpener - Cherry.step, ScottoOpener - Kailh.step, ScottoOpener - Kailh.stl]
2023-07-30 Remove text for better printability
    [ScottoOpener - Cherry.step, ScottoOpener - Cherry.stl, ScottoOpener - Kailh.step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]
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2023-07-31 Add hole to ScottoOpener
    [ScottoOpener - Cherry.step, ScottoOpener - Cherry.stl, ScottoOpener - Kailh.step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]
2023-07-31 Add updated files along with 10u
    [ScottoCaps - 1.00u.step, ScottoCaps - 1.00u.stl, ScottoCaps - 1.25u.step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]
2023-08-01 Fix rotation
    [ScottoOpener - Cherry.step, ScottoOpener - Cherry.stl, ScottoOpener - Kailh.step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]
2023-08-01 Add text back to opener
    [ScottoOpener - Cherry.step, ScottoOpener - Cherry.stl, ScottoOpener - Kailh.step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]
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2023-08-18 Revert diode cutout
    [ScottoCoiler - ScottoCoiler (Top).stl]
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2023-08-19 Update dimensions for glass caps and add 1.75u
    [ScottoCaps (Glass) - 1.00u.step, ScottoCaps (Glass) - 1.00u.stl, ScottoCaps (Glass) - 1.25u.step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]
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2023-10-19 Fix ScottoCaps folder
    [ScottoCaps (Standard) - 1.00u.step, ScottoCaps (Standard) - 1.00u.stl, ScottoCaps (Standard) - 1.25u.step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]
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2023-10-19 Add updated Chamfer, Fillet, and Sharp ScottoCaps (Standard)
    [ScottoCaps (Standard) - Chamfer (1.00u).step, ScottoCaps (Standard) - Chamfer (1.00u).stl, ScottoCaps (Standard) - Chamfer (1.25u).step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]
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2023-11-06 Revert ScottoCaps Changes
    [ScottoCaps (Comic Sans) - Text.step, ScottoCaps (Comic Sans) - Text.stl, ScottoCaps (Legends) - Text.step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]
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2023-11-26 Fix chamfer for 2.00u ScottoCap Blank
    [2.00u.step, 2.00u.stl]
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2023-12-18 Add STEP files and Readme for ScottoCaps Scooped
    [1.00u (Concave).step, 1.00u (Convex).step, 1.25u (Concave).step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]
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2023-12-19 Add 0.75mm spacing and make homing but more pronounced
    [0 (1.00u).3mf, 0 (2.00u).3mf, 1.00u (Concave).3mf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]
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2023-12-20 Fix 3.00u blank stems
    [3.00u (Concave).3mf, 3.00u (Concave).step, 3.00u (Convex).3mf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]
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2023-12-27 Change stem dimension to 5.6mm from 5.8mm to prevent rare binding
    [0 (1.00u).3mf, 0 (2.00u).3mf, 1.00u (Concave).3mf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]
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2023-12-27 Fix raw stems
    [ScottoCaps (Scooped) - Raw.step]
2023-12-27 Fix Convex height
    [1.00u (Concave).3mf, 1.00u (Concave).step, 1.00u (Convex).3mf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]
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2023-12-31 Add one more screw for stability
    [ScottoAlp - Case (4x12_7).step, ScottoAlp - Case (4x12_7).stl, ScottoAlp - Plate (4x12_7).step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]
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2024-01-02 Fix case
    [ScottoKatana - Gasket Bottom (ATmega32U4 Pro Micro).step, ScottoKatana - Gasket Bottom (RP2040 Pro Micro).step, ScottoKatana - Gasket Plate.step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]
2024-01-03 Add 2 tolerances for gasket plate
    [ScottoKatana - Gasket Plate (0.25mm Tolerance).step, ScottoKatana - Gasket Plate (0.25mm Tolerance).stl, ScottoKatana - Gasket Plate (0.5mm Tolerance).step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]
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2024-03-13 Update flipped schematic
2024-03-16 Fix silkscreen for nice nano
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2024-05-18 Add new 1.50u and 1.25u keys for ScottoBubble
    [Back (1.50u).3mf, Caps (1.25u).3mf, Caps (1.50u).3mf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]
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2024-05-26 Fix unconnected tracks
    [ScottoModules.kicad_pcb]
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2024-05-26 Fix JLCPCB Rotation
    [ScottoModules.kicad_pcb, ScottoModules.kicad_sch]
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2024-05-26 Update stabilized keys to have top facing screws
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2024-06-25 Add Choc HS 1.00u, MX Solder 1.00u reversable, testpoint, and 2765 joystick
2024-06-28 Fix missing 3x6 case
    [ScottoWing (PCB Edition) - 3x6.3mf, ScottoWing (PCB Edition) - 3x6.step]
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2024-07-13 Rename reset to boot button for clarity
    [ScottoModules.kicad_sch]
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2024-09-14 Add new flat caps and update shapr3d file
    [0 (2.00u).3mf, Asterisk.3mf, Enter (2.00u).3mf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]
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2024-11-01 Fix missing indents
    [ScottoErgo - Case.step, ScottoErgo - Case.stl]
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2025-03-08 Update to correct files
    [Scotto69 (PCB Edition) - Angle (5°).step, Scotto69 (PCB Edition) - Angle (5°).stl, Scotto69 (PCB Edition) - Case (Bottom).step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]
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2025-07-13 Update firmware to use solenoid buzz
    [config.h]
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2025-11-18 Replace ESC with TAB
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2025-11-27 Fix geometry
    [ScottoFrog (PCB Edition) - Plate.step, ScottoFrog (PCB Edition) - Plate.stl]
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2026-06-05 Add RP2040 Flipped MX reverse mount
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

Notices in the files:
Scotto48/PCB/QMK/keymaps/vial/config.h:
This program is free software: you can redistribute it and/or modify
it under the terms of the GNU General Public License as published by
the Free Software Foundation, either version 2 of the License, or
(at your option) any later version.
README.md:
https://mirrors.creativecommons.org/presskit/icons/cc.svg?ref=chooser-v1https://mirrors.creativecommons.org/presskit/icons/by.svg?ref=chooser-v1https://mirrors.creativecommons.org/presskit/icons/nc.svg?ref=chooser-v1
